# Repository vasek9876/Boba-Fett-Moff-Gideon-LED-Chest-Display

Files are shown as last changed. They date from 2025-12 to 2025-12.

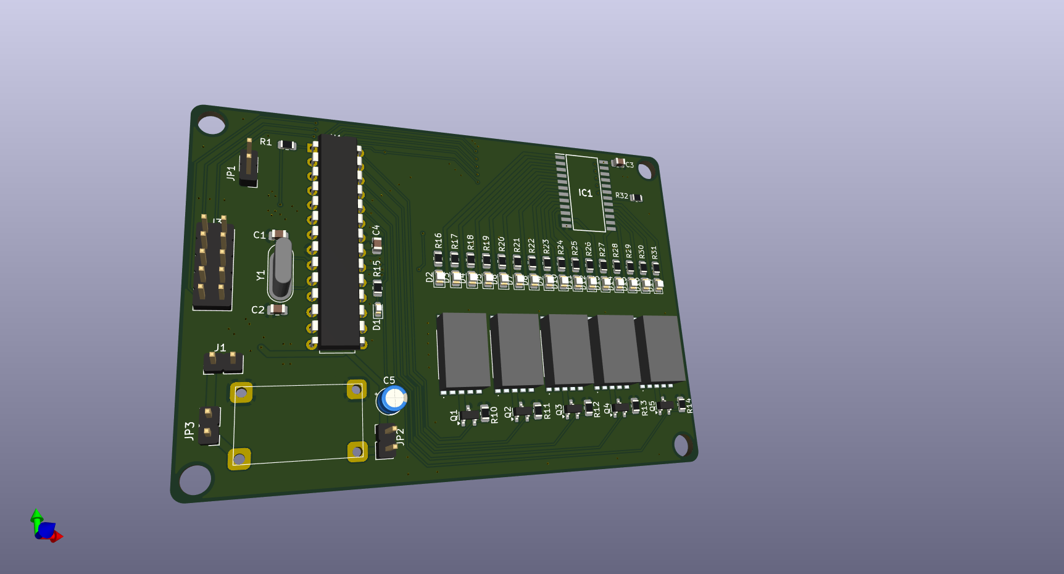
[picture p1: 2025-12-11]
PCB/MODEL/Mandalorian_and_Moff_Gideon.png

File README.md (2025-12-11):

# Boba-Fett-Moff-Gideon-LED-Chest-Display

Boba Fett / Moff Gideon LED Chest Display for cosplay or props.

This product is inspired by these [commercially accessible solution](https://www.etsy.com/au/listing/1456479470/high-quality-boba-fettmoff-gideon-led) - but made for a smaller chestplate
Function implemented to emulate the same functions as in this image - The current version of the code does not implement the last display function.



## Solution





- Multiplexed LED bar display for chest armor effects
- Gradual power-up sequence to detect brownout correctly
- Battery voltage monitoring with low-voltage deep sleep and green LED alert

## Usage
- Power the device with a suitable battery (9 V battery or use a 5–10 V battery, but a 5-18 V battery is suitable)
- LEDs gradually light up on startup when turned ON
- If battery voltage is too low, the circuit enters deep sleep and indicates the error with the green LED and "E" on the first segment display.
- It is possible to connect the powerbank directly to the pins used for the 9 V battery, but the consumption of the circuit is approximately 100 mA, so the circuit is not ready to run on a powerbank continuously (the powerbank turns off after a time because of its internal protection circuit)
  - Some old power banks are ready to be used with this device, but it is not guaranteed.
  - You can use, for example, this device [keep-alive device](https://www.sotabeams.co.uk/usb-battery-pack-keep-alive-load/) for the current version of the device.
- By the calculation, the 9 V battery should keep the device on for 3 - 5 hours, but it depends on the battery capacity and the battery's internal resistance.

## Programming
- Microcontroller: **ATmega328PB**
- Programming via **USB-ASP** device
- Use [AVRDUDE](https://github.com/avrdudes/avrdude) for direct programming; select "USBasp (USBasp ISP and TPI programmer)"
- Fuse settings for this project:
  - Low: `0xE2`
  - High: `0xD9`
  - Extended: `0xFD`
  - Lock Bits: `0xFF`
  - Verify fuses with [Engbedded Fuse Calculator](https://www.engbedded.com/fusecalc/)

- Firmware source code is included in [SW](https://github.com/vasek9876/Boba-Fett-Moff-Gideon-LED-Chest-Display/tree/all/sw)

## Notes

Untitled Diagram (2)

- Ensure proper power supply to avoid brownout during startup (>5 V)
- Multiplexing is handled in firmware
- The rapid switching of LEDs may generate audible noise from the power supply or nearby components; this is normal and does not indicate a fault.

## Goal and further developement

- The goal of this open hw is to make this relatively simple custom device based on AtMega accessible for anyone.
- The current development is stopped, but there are known issues, which will be resolved in a few months.

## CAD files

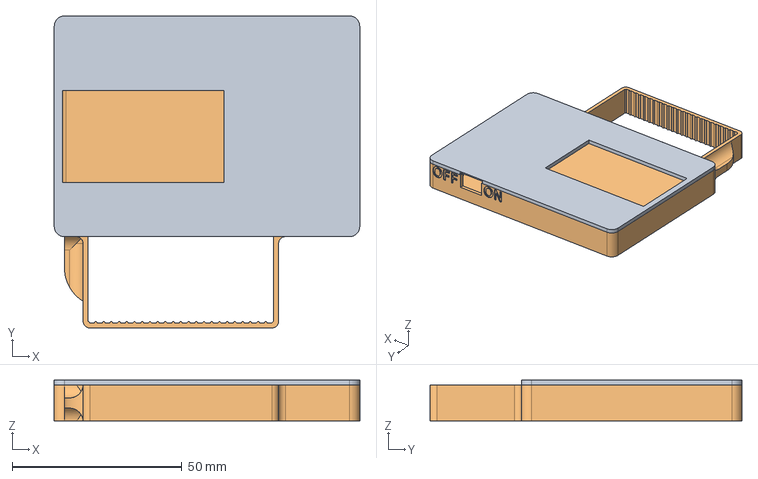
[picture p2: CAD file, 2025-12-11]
hw/box.step
90.0 x 91.9 x 12.0 mm

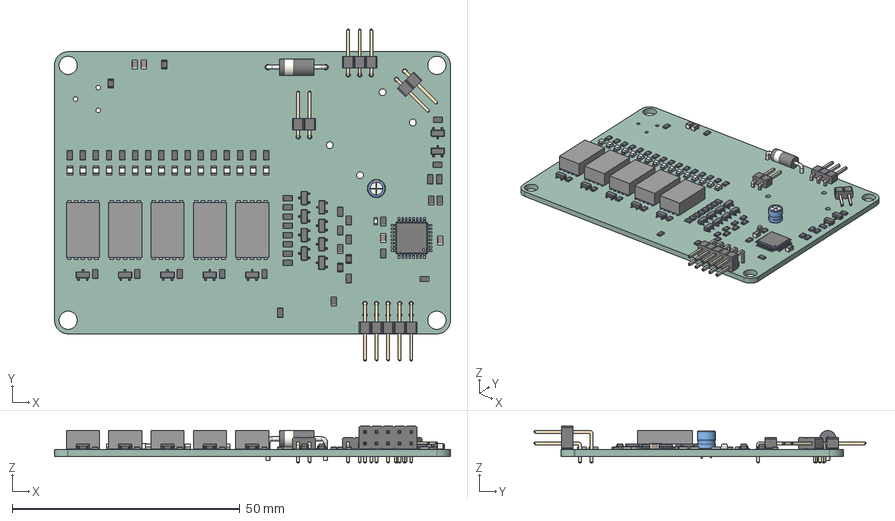
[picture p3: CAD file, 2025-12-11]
PCB/MODEL/Mandalorian_and_Moff_Gideon.step
87.0 x 72.8 x 8.08 mm
R_0805_2012Metric x 50
SOT_23 x 15
D_DO-15_P12.70mm_Horizontal
PinHeader_1x03_P254mm_Horizontal
LED_0805_2012Metric x 16
ASSEMBLY x 5
C_0805_2012Metric x 4
PinHeader_1x02_P254mm_Horizontal x 2
LED_0603_1608Metric
PinHeader_2x05_P254mm_Horizontal
CP_Radial_D40mm_P200mm
TQFP_32_7x7mm_P08mm
Mandalorian_and_Moff_Gideon_PCB

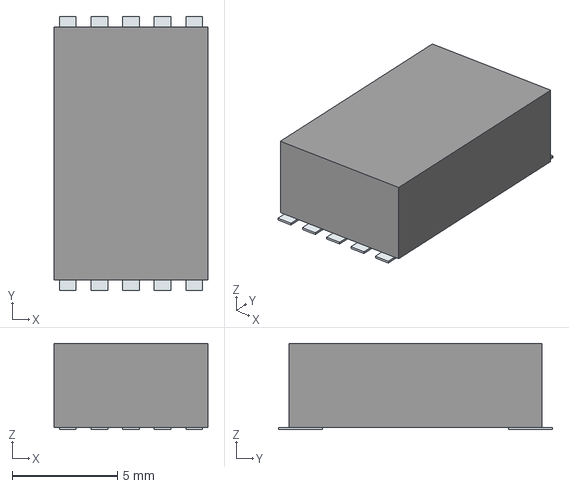
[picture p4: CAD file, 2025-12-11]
PCB/LIB_157112B12700/157112B12700/3D/157112B12700.stp
7.30 x 13.0 x 4.10 mm
Pins

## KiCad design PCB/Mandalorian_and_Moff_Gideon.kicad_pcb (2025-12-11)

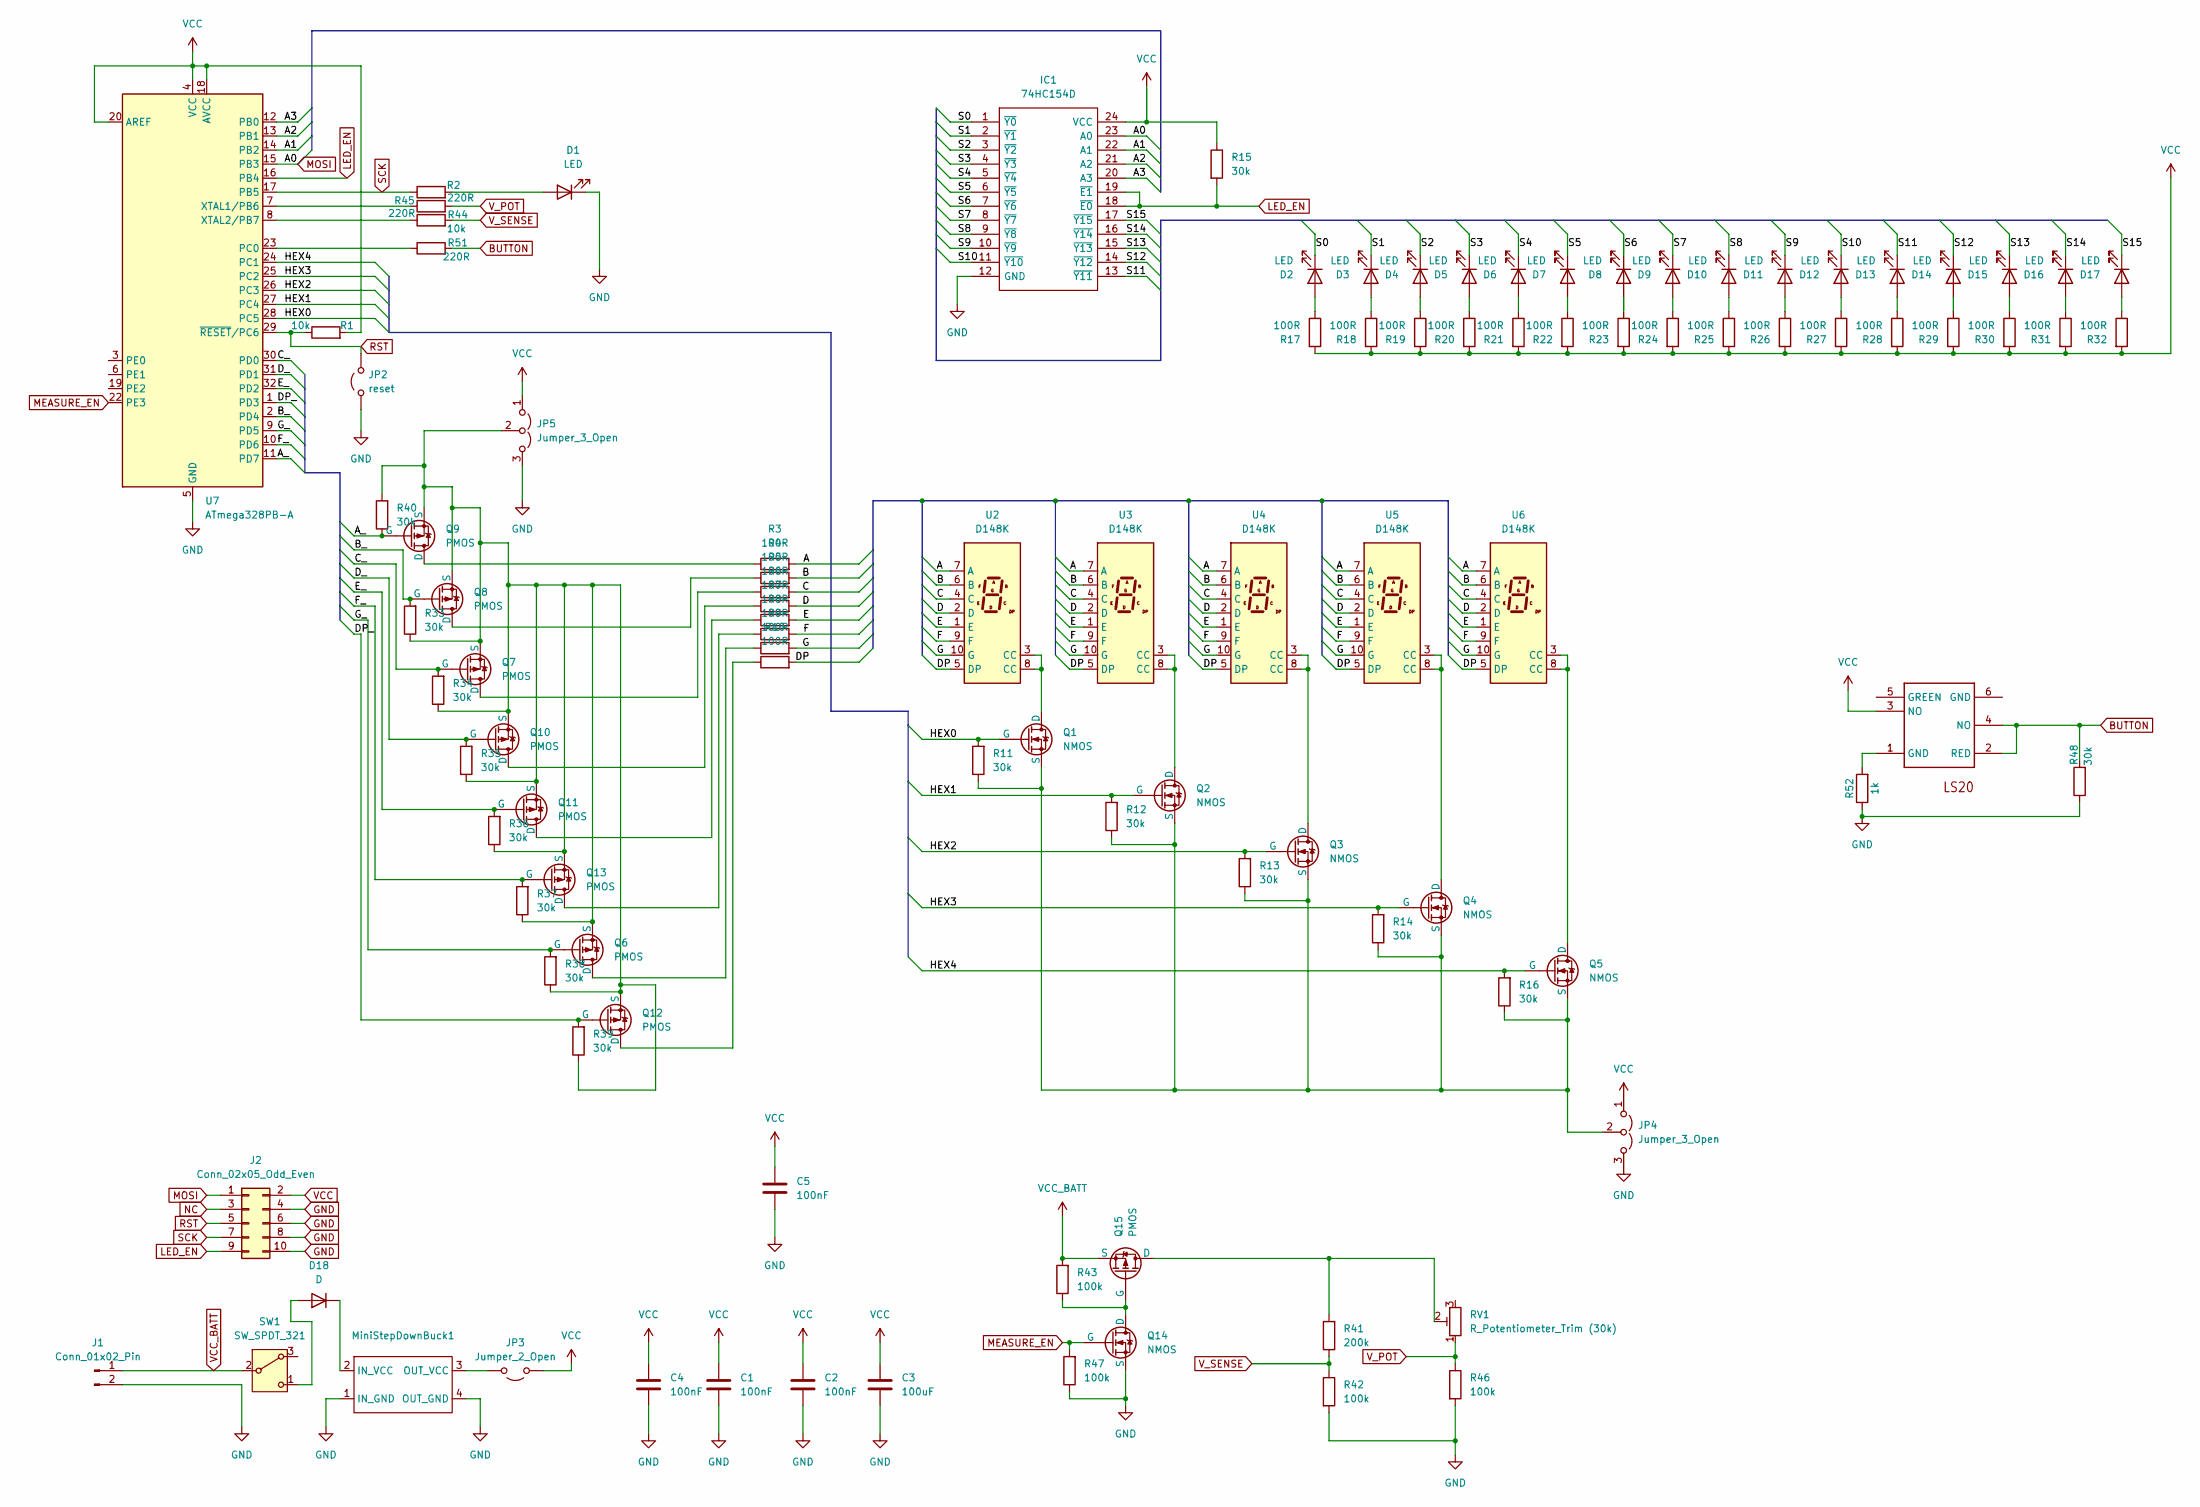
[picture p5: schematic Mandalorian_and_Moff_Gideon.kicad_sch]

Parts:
C1, C2, C4, C5: 100nF; C_0805_2012Metric
C3: 100uF; CP_Radial_D4.0mm_P2.00mm
D1: LED; LED_0603_1608Metric
D2, D3, D4, D5, D6, D7, D8, D9, D10, D11, D12, D13, D14, D15, D16, D17: LED; LED_0805_2012Metric
D18: D; D_DO-15_P12.70mm_Horizontal
IC1: 74HC154D; SOIC127P1032X265-24N; Manufacturer_Part_Number 74HC154D; Mouser Part Number 771-74HC154D
J1: Conn_01x02_Pin; PinHeader_1x02_P2.54mm_Horizontal
J2: Conn_02x05_Odd_Even; PinHeader_2x05_P2.54mm_Horizontal
JP2: reset; SolderJumper-2_P1.3mm_Open_RoundedPad1.0x1.5mm
JP3: Jumper_2_Open; PinHeader_1x02_P2.54mm_Horizontal
JP4, JP5: Jumper_3_Open; SolderJumper-3_P1.3mm_Open_RoundedPad1.0x1.5mm
LS20: LS20
MiniStepDownBuck1: Step_down_360
Q1, Q2, Q3, Q4, Q5, Q14: NMOS; SOT-23
Q6, Q7, Q8, Q9, Q10, Q11, Q12, Q13, Q15: PMOS; SOT-23
R1, R44: 10k; R_0805_2012Metric
R2, R45, R51: 220R; R_0805_2012Metric
R3, R4, R5, R6, R7, R8, R9, R10, R17, R18, R19, R20, R21, R22, R23, R24, R25, R26, R27, R28, R29, R30, R31, R32: 100R; R_0805_2012Metric
R11, R12, R13, R14, R15, R16, R33, R34, R35, R36, R37, R38, R39, R40, R48: 30k; R_0805_2012Metric
R41: 200k; R_0805_2012Metric
R42, R43, R46, R47: 100k; R_0805_2012Metric
R52: 1k; R_0805_2012Metric
RV1: R_Potentiometer_Trim (30k); Potentiometer_Runtron_RM-065_Vertical
SW1: SW_SPDT_321; PinHeader_1x03_P2.54mm_Horizontal
U2, U3, U4, U5, U6: D148K; 157112B12700
U7: ATmega328PB-A; TQFP-32_7x7mm_P0.8mm

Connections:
/A: R3.2, U2.7 (A), U3.7 (A), U4.7 (A), U5.7 (A), U6.7 (A)
/A1: IC1.22 (A1), U7.14 (PB2)
/A2: IC1.21 (A2), U7.13 (PB1)
/A3: IC1.20 (A3), U7.12 (PB0)
/A_: Q9.1 (G), R40.1, U7.11 (PD7)
/B: R4.2, U2.6 (B), U3.6 (B), U4.6 (B), U5.6 (B), U6.6 (B)
/B_: Q8.1 (G), R33.2, U7.2 (PD4)
/C: R5.2, U2.4 (C), U3.4 (C), U4.4 (C), U5.4 (C), U6.4 (C)
/C_: Q7.1 (G), R34.2, U7.30 (PD0)
/D: R6.2, U2.2 (D), U3.2 (D), U4.2 (D), U5.2 (D), U6.2 (D)
/DP: R10.2, U2.5 (DP), U3.5 (DP), U4.5 (DP), U5.5 (DP), U6.5 (DP)
/DP_: Q12.1 (G), R39.2, U7.1 (PD3)
/D_: Q10.1 (G), R35.2, U7.31 (PD1)
/E: R7.2, U2.1 (E), U3.1 (E), U4.1 (E), U5.1 (E), U6.1 (E)
/E_: Q11.1 (G), R36.2, U7.32 (PD2)
/F: R8.2, U2.9 (F), U3.9 (F), U4.9 (F), U5.9 (F), U6.9 (F)
/F_: Q13.1 (G), R37.2, U7.10 (PD6)
/G: R9.2, U2.10 (G), U3.10 (G), U4.10 (G), U5.10 (G), U6.10 (G)
/G_: Q6.1 (G), R38.2, U7.9 (PD5)
/HEX0: Q1.1 (G), R11.2, U7.28 (PC5)
/HEX1: Q2.1 (G), R12.2, U7.27 (PC4)
/HEX2: Q3.1 (G), R13.2, U7.26 (PC3)
/HEX3: Q4.1 (G), R14.2, U7.25 (PC2)
/HEX4: Q5.1 (G), R16.2, U7.24 (PC1)
/S0: D2.1 (K), IC1.1 (~Y0)
/S1: D3.1 (K), IC1.2 (~Y1)
/S2: D4.1 (K), IC1.3 (~Y2)
/S3: D5.1 (K), IC1.4 (~Y3)
/S4: D6.1 (K), IC1.5 (~Y4)
/S5: D7.1 (K), IC1.6 (~Y5)
/S6: D8.1 (K), IC1.7 (~Y6)
/S7: D9.1 (K), IC1.8 (~Y7)
/S8: D10.1 (K), IC1.9 (~Y8)
/S9: D11.1 (K), IC1.10 (~Y9)
/S10: D12.1 (K), IC1.11 (~Y10)
/S11: D13.1 (K), IC1.13 (~Y11)
/S12: D14.1 (K), IC1.14 (~Y12)
/S13: D15.1 (K), IC1.15 (~Y13)
/S14: D16.1 (K), IC1.16 (~Y14)
/S15: D17.1 (K), IC1.17 (~Y15)
BUTTON: LS20.2 (RED), LS20.4 (NO), R48.2, R51.2
GND: C1.2, C2.2, C3.2, C4.2, C5.2, D1.1 (K), IC1.12 (GND), J1.2, J2.4, J2.6, J2.8, J2.10, JP2.1 (A), JP4.3 (B), JP5.3 (B), MiniStepDownBuck1.1 (IN_GND), MiniStepDownBuck1.4 (OUT_GND), Q14.2 (S), R42.2, R46.2, R47.1, R48.1, R52.1, U7.5 (GND), U7.21 (GND)
LED_EN: IC1.18 (~E0), IC1.19 (~E1), J2.9, R15.2, U7.16 (PB4)
MEASURE_EN: Q14.1 (G), R47.2, U7.22 (PE3)
MOSI: IC1.23 (A0), J2.1, U7.15 (PB3)
NC: J2.3
unnamed: D1.2 (A), R2.2
unnamed: D2.2 (A), R17.1
unnamed: D3.2 (A), R18.1
unnamed: D4.2 (A), R19.1
unnamed: D5.2 (A), R20.1
unnamed: D6.2 (A), R21.1
unnamed: D7.2 (A), R22.1
unnamed: D8.2 (A), R23.1
unnamed: D9.2 (A), R24.1
unnamed: D10.2 (A), R25.1
unnamed: D11.2 (A), R26.1
unnamed: D12.2 (A), R27.1
unnamed: D13.2 (A), R28.1
unnamed: D14.2 (A), R29.1
unnamed: D15.2 (A), R30.1
unnamed: D16.2 (A), R31.1
unnamed: D17.2 (A), R32.1
unnamed: D18.2 (A), SW1.1 (C)
unnamed: D18.1 (K), MiniStepDownBuck1.2 (IN_VCC)
unnamed: JP3.2 (B), MiniStepDownBuck1.3 (OUT_VCC)
unnamed: JP4.2 (C), Q1.2 (S), Q2.2 (S), Q3.2 (S), Q4.2 (S), Q5.2 (S), R11.1, R12.1, R13.1, R14.1, R16.1
unnamed: JP5.2 (C), Q6.2 (S), Q7.2 (S), Q8.2 (S), Q9.2 (S), Q10.2 (S), Q11.2 (S), Q12.2 (S), Q13.2 (S), R33.1, R34.1, R35.1, R36.1, R37.1, R38.1, R39.1, R40.2
unnamed: LS20.1 (GND), R52.2
unnamed: Q1.3 (D), U2.3 (CC), U2.8 (CC)
unnamed: Q2.3 (D), U3.3 (CC), U3.8 (CC)
unnamed: Q3.3 (D), U4.3 (CC), U4.8 (CC)
unnamed: Q4.3 (D), U5.3 (CC), U5.8 (CC)
unnamed: Q5.3 (D), U6.3 (CC), U6.8 (CC)
unnamed: Q6.3 (D), R9.1
unnamed: Q7.3 (D), R5.1
unnamed: Q8.3 (D), R4.1
unnamed: Q9.3 (D), R3.1
unnamed: Q10.3 (D), R6.1
unnamed: Q11.3 (D), R7.1
unnamed: Q12.3 (D), R10.1
unnamed: Q13.3 (D), R8.1
unnamed: Q14.3 (D), Q15.1 (G), R43.1
unnamed: Q15.3 (D), R41.2, RV1.2
unnamed: R51.1, U7.23 (PC0)
unnamed: R45.1, U7.7 (XTAL1/PB6)
unnamed: R44.1, U7.8 (XTAL2/PB7)
RST: J2.5, JP2.2 (B), R1.1, U7.29 (~RESET/PC6)
SCK: J2.7, R2.1, U7.17 (PB5)
VCC: C1.1, C2.1, C3.1, C4.1, C5.1, IC1.24 (VCC), J2.2, JP3.1 (A), JP4.1 (A), JP5.1 (A), LS20.3 (NO), R1.2, R15.1, R17.2, R18.2, R19.2, R20.2, R21.2, R22.2, R23.2, R24.2, R25.2, R26.2, R27.2, R28.2, R29.2, R30.2, R31.2, R32.2, U7.4 (VCC), U7.18 (AVCC), U7.20 (AREF)
VCC_BATT: J1.1, Q15.2 (S), R43.2, SW1.2 (B)
V_POT: R45.2, R46.1, RV1.1
V_SENSE: R41.1, R42.1, R44.2

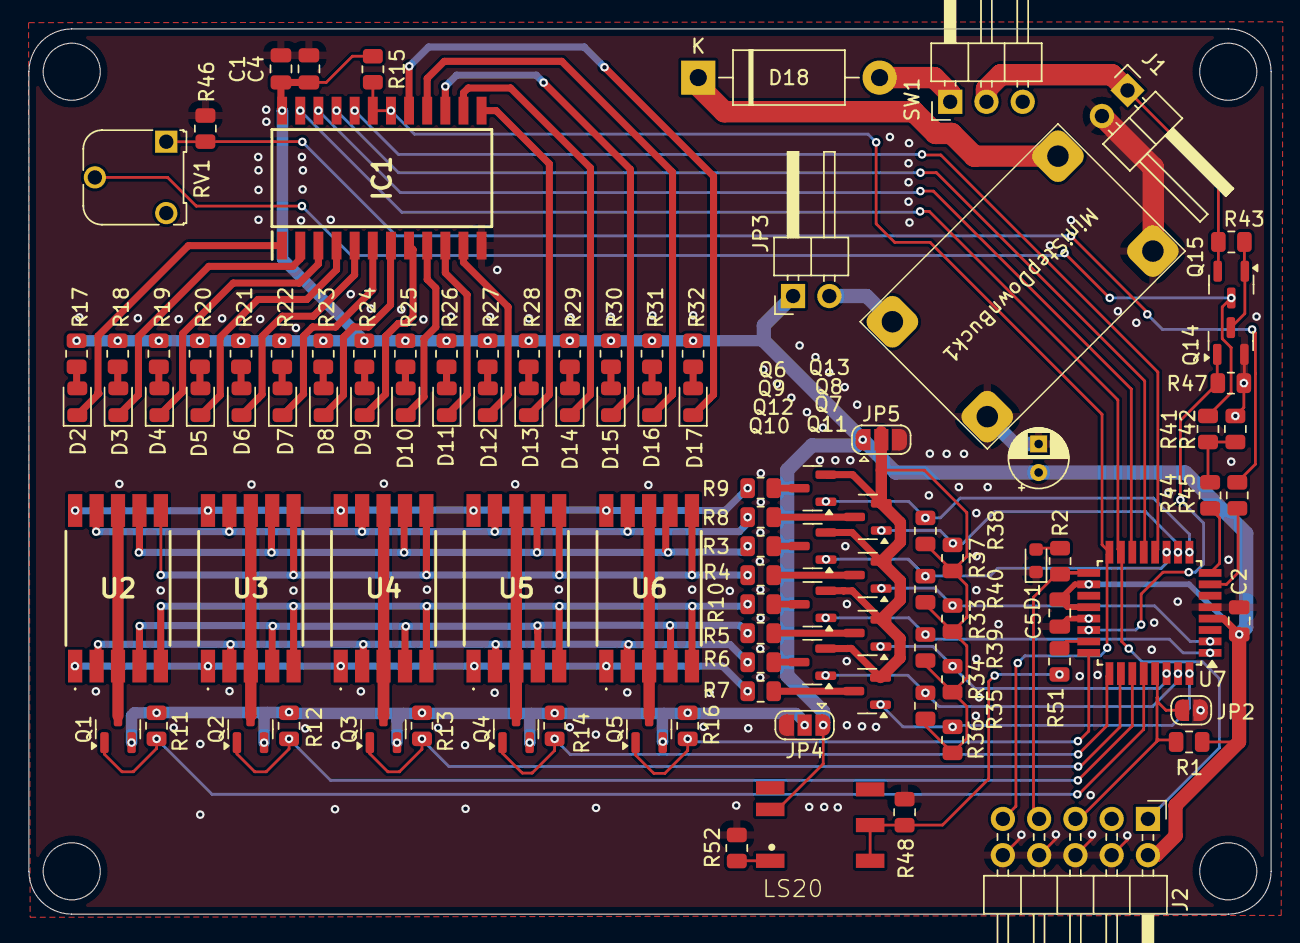
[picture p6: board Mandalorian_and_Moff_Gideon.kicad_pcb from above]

Board: 2 copper layers, 87.0 x 62.0 mm, 105 parts (0 on the bottom side), 92 nets.

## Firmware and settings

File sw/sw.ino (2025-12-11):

#include "defaults.h"
#include "functions.h"
#include "analog.h"
//#include "bod_detect.cpp"

//#define NOP __asm__ __volatile__ ("nop\n\t") // Define the NOP instruction

bool bod_triggered = false;

void setup_bod_flag() {
  uint8_t status = MCUSR;

  // Clear flags immediately after reading to prepare for next event
  MCUSR = 0; 
  bod_triggered = true;
  led_on();

  if (status & (1 << BORF)) {
    bod_triggered = true;
    led_on();
    // Brown-out Reset occurred
    // {Link: www.avrfreaks.net https://www.avrfreaks.net/s/topic/a5C3l000000UY10EAG/t144548}
  }

  if (status & (1 << PORF)) {
    bod_triggered = false;
    led_off();
    // Power-on Reset occurred (also clears BORF if it happened)
  }
}

void getVoltageDigits(float v, int digits[5]) {
    int scaled = v*10000*2 + OFFSET*1000;

    digits[0] = (scaled / 1000) % 10;
    digits[1] = (scaled / 100)  % 10;
    digits[2] = (scaled / 10)   % 10;
    digits[3] =  scaled % 10;
    digits[4] = 0; 
}

void preloop() {
  float v;
  int digits[5];
  for (int n = 0; n < 3; n++) {
    v = readVoltage();
    getVoltageDigits(v, digits);

    for (int k = 0; k < 100; k++) {
      lcd_write(0, PATTERN_U);
      lcd_write(1, pattern_numbers[digits[3]]);
      lcd_write(2, pattern_numbers[digits[2]]);
      lcd_write(3, pattern_numbers[digits[1]]);
      lcd_write(4, pattern_numbers_DP[digits[0]]);
    }
  }
}

void setup() {
  setup_bod_flag();

  // ----------------- NEW --------------------
  DDRB |= (1 << LED_PIN); // led setup as output

  // ADC MEASURE
  // 1. Set PC0 (ADC0) as input pin
  // --- ADC MĚŘENÍ ---
  // 1. Nastavte PC0 (ADC0) jako vstup (ruční nastavení DDRC)
  DDRC &= ~(1 << PC0); 

  // 2. Nastavte Referenci (AVcc) a kanál (ADC0)
  ADMUX = (1 << REFS0); 
  
  // 3. Povolte ADC, Prescaler 128 a vynulujte ADCSRB
  ADCSRA = (1 << ADEN) | (1 << ADPS2) | (1 << ADPS1) | (1 << ADPS0);
  ADCSRB = 0; // K zamezení interních měření

  // Set PE3 as OUTPUT and initialize to LOW
  DDRE |= (1 << MEASURE_EN_BIT);  // PE3 as output
  PORTE &= ~(1 << MEASURE_EN_BIT);  // Initialize to LOW

  DDRD = 0xFF;
  LCD_DDR |= LCD_MASK;  // outputs
  BAR_DDR |= BAR_MASK;  // outputs
  BAR_EN_DDR |= (1 << BAR_EN_BIT);

  // Start with all off
  LCD_PORT &= ~LCD_MASK;
  BAR_PORT &= ~BAR_MASK;

  // ENABLE
  //BAR_EN_PORT &= ~(1 << BAR_EN_BIT);

  //DISABLE
  BAR_EN_PORT |= (1 << BAR_EN_BIT);

  // Configure Timer1 once
  TCCR1A = 0;            // Normal mode
  TCCR1B = (1 << CS10);  // Prescaler = 1

  if (bod_triggered)
  {
    for (int n = 0; n < 1; n++) {
      for (int k = 0; k < 100; k++) {
      lcd_write(4, PATTERN_E);
      delay(1);
      }
    }
  }
  else
  {
    bar_test();

    preloop();
  }

  ADCSRA &= ~(1 << ADEN); // disable ADC


  PRR = (1 << PRTWI) |    // Disable TWI (I2C)
          (1 << PRSPI) |    // Disable SPI
          (1 << PRUSART0) | // Disable USART (Serial)
          (1 << PRTIM2);   // Disable Timer 2
          //(1 << PRTIM0);    // Disable Timer 0 (Timer 1 is kept for LCD/Bar timing)
  

}

void loop() {
  if (bod_triggered) {
    set_sleep_mode(SLEEP_MODE_PWR_SAVE);
    sleep_enable();
  }
  else
  {
  for (int i = 0; i < REPEAT_FUNC1; i++) {
    call_function(pattern5, 9);
  }

  for (int i = 0; i < REPEAT_FUNC2; i++) {
    call_function(pattern2, 6);
  }

  for (int i = 0; i < REPEAT_FUNC3; i++) {
    call_function(pattern1, 11);
  }

  BAR_EN_PORT |= (1 << BAR_EN_BIT);
  for (int i = 0; i < REPEAT_FUNC4; i++) {
    call_bare_function(pattern4);
  }

  for (int i = 0; i < REPEAT_FUNC5; i++) {
    call_function(pattern2, 3);
  }

  for (int i = 0; i < REPEAT_FUNC6; i++) {
    call_function(pattern3, 0);
  }
  }
}

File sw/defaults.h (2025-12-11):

#ifndef defaults_h
#define defaults_h

#include <avr/io.h>

#ifdef OLD

// 88888
#define PATTERN_51 0b11101111
#define PATTERN_52 0b11101111
#define PATTERN_53 0b11101111
#define PATTERN_54 0b11101111
#define PATTERN_55 0b11101111

// DUEPI
#define PATTERN_21 0b00000010
#define PATTERN_22 0b10001111
#define PATTERN_23 0b11000111
#define PATTERN_24 0b11101010
#define PATTERN_25 0b11101001

// AEAOE
#define PATTERN_11 0b10000011
#define PATTERN_12 0b11101100
#define PATTERN_13 0b10101101
#define PATTERN_14 0b11000111
#define PATTERN_15 0b10100111

// caj
#define PATTERN_41 0b00000101
#define PATTERN_42 0b10000010
#define PATTERN_43 0b01000100
#define PATTERN_44 0b00100010
#define PATTERN_45 0b00001001

// DUEPI again

// H5291
#define PATTERN_31 0b10000010
#define PATTERN_32 0b00101111
#define PATTERN_33 0b11001101
#define PATTERN_34 0b01100011
#define PATTERN_35 0b10101011

#else

// 88888
#define PATTERN_51 0b00001000
#define PATTERN_52 0b00001000
#define PATTERN_53 0b00001000
#define PATTERN_54 0b00001000
#define PATTERN_55 0b00001000

// DUEPI
#define PATTERN_21 0b10111111
#define PATTERN_22 0b00001011
#define PATTERN_23 0b00011001
#define PATTERN_24 0b10101000
#define PATTERN_25 0b11001000

// AEAOE
#define PATTERN_11 0b10011011
#define PATTERN_12 0b01101000
#define PATTERN_13 0b01001010
#define PATTERN_14 0b00011001
#define PATTERN_15 0b00011010

// caj
#define PATTERN_41 0b01011111
#define PATTERN_42 0b10111011
#define PATTERN_43 0b01111101
#define PATTERN_44 0b10111110
#define PATTERN_45 0b11001111

// DUEPI again

// H5291
#define PATTERN_31 0b10111011
#define PATTERN_32 0b00001110
#define PATTERN_33 0b01001001
#define PATTERN_34 0b10011100
#define PATTERN_35 0b10001010

// now afgbhedc (default abcdefgh)

#define PATTERN_0 0b00101000  // 0 // OK
#define PATTERN_1 0b10111011  // 1 // OK
#define PATTERN_2 0b01001001  // 2 // OK
#define PATTERN_3 0b01001100  // 3 // OK
#define PATTERN_4 0b10001110  // 4 // OK
#define PATTERN_5 0b00011100  // 5
#define PATTERN_6 0b00011000  // 6
#define PATTERN_7 0b01101110  // 7
#define PATTERN_8 0b00001000  // 8
#define PATTERN_9 0b00001110  // 9
#define PATTERN_E 0b00011001  // E

#define PATTERN_0_DP 0b00100000  // 0 // OK
#define PATTERN_1_DP 0b10110011  // 1 // OK
#define PATTERN_2_DP 0b01000001  // 2 // OK
#define PATTERN_3_DP 0b01000100  // 3 // OK
#define PATTERN_4_DP 0b10000110  // 4 // OK
#define PATTERN_5_DP 0b00010100  // 5
#define PATTERN_6_DP 0b00010000  // 6
#define PATTERN_7_DP 0b01100110  // 7
#define PATTERN_8_DP 0b00000000  // 8
#define PATTERN_9_DP 0b00000110  // 9

#define PATTERN_U 0b10101000

#endif

#ifdef TEST



#define PATTERN_11 0b01111111
#define PATTERN_12 0b01110111
#define PATTERN_13 0b01111011
#define PATTERN_14 0b01111101
#define PATTERN_15 0b01111110

#endif

// in sec
#define REPEAT_FUNC1 27*2 // 0.49
#define REPEAT_FUNC2 28*2 // 0.51
#define REPEAT_FUNC3 26*2 // 0.48
#define REPEAT_FUNC4 40*2 // 0.72  
#define REPEAT_FUNC5 30*2 // 0.54
#define REPEAT_FUNC6 27*2 // 0.50

// digits

const byte DIGITS[10] = {
    PATTERN_0,
    PATTERN_1,
    PATTERN_2,
    PATTERN_3,
    PATTERN_4,
    PATTERN_5,
    PATTERN_6,
    PATTERN_7,
    PATTERN_8,
    PATTERN_9
};


const byte bar_map[16][4] = {
  // D, B, A, C (DCBA - 1111)
  {0,0,0,0},
  {0,0,1,0},
  {0,1,0,0},
  {0,1,1,0},
  {0,0,0,1},
  {0,0,1,1},
  {0,1,0,1},
  {0,1,1,1},

  {1,0,0,0},
  {1,0,1,0},
  {1,1,0,0},
  {1,1,1,0},
  {1,0,0,1},
  {1,0,1,1},
  {1,1,0,1},
  {1,1,1,1},
};

// Old
#ifdef OLD
const byte bar_map[16][4] = {
    {0,0,0,1},
    {0,1,0,0},
    {0,0,1,0},
    {0,0,0,0},
    {1,0,0,0},
    {1,1,0,0},
    {0,1,0,1},
    {1,1,0,1},
    {0,0,1,0},
    {1,0,1,0},
    {0,0,1,1},
    {1,0,1,1},
    {0,1,1,0},
    {1,1,1,0},
    {0,1,1,1},
    {1,1,1,1}
};
#endif



const byte pattern_numbers[] = {PATTERN_0, PATTERN_1, PATTERN_2, PATTERN_3, PATTERN_4,
                                PATTERN_5, PATTERN_6, PATTERN_7, PATTERN_8, PATTERN_9};

const byte pattern_numbers_DP[] = {PATTERN_0_DP, PATTERN_1_DP, PATTERN_2_DP, PATTERN_3_DP, PATTERN_4_DP,
                                PATTERN_5_DP, PATTERN_6_DP, PATTERN_7_DP, PATTERN_8_DP, PATTERN_9_DP};


const byte pattern1[] = {PATTERN_11, PATTERN_12, PATTERN_13, PATTERN_14, PATTERN_15};
const byte pattern2[] = {PATTERN_21, PATTERN_22, PATTERN_23, PATTERN_24, PATTERN_25};
const byte pattern3[] = {PATTERN_31, PATTERN_32, PATTERN_33, PATTERN_34, PATTERN_35};
const byte pattern4[] = {PATTERN_41, PATTERN_42, PATTERN_43, PATTERN_44, PATTERN_45};
const byte pattern5[] = {PATTERN_51, PATTERN_52, PATTERN_53, PATTERN_54, PATTERN_55};



// LED pin
#define LED_PIN PB5

// LCD segments on PORTC bits 5..1
// const int lcd_addr[] = { A5, A4, A3, A2, A1 };  // Segments: PC5,PC4,PC3,PC2,PC1
#define LCD_PORT PORTC
#define LCD_DDR DDRC
#define LCD_MASK ((1 << PC5) | (1 << PC4) | (1 << PC3) | (1 << PC2) | (1 << PC1))

#define NUM_SEG 5  // Number of LCD segments

// Bar LEDs on PORTB bits 0,2,3,1 (in that order)
// const int bar_leds[] = { 8, 10, 11, 9 };  // PB0, PB2, PB3, PB1
#define BAR_PORT PORTB
#define BAR_DDR DDRB
#define BAR_MASK ((1 << PB0) | (1 << PB2) | (1 << PB3) | (1 << PB1))

// map bits to actual PORTB bits
static const uint8_t barBits[4] = { (1 << PB0), (1 << PB2), (1 << PB3), (1 << PB1) };

// const int bar_leds_en = 12;  // PB4
#define BAR_EN_PORT PORTB
#define BAR_EN_DDR DDRB
#define BAR_EN_BIT PB4

#endif

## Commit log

2025-12-11 PCB
    kicad - PCB last version
    - badly routed V_BAT measurement and the analog pins - they are not at analog inputs
    - the reverse polarity protection is not ok with deiode - next iteration should have the ideal diode using Pmos
    [157112B12700.stp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]
2025-12-11 Last firmware with loading and voltage indication
    - In the last firmware, the first step tries to turn on all bar LEDs gradually, which is necessary to slowly increase power consumption and check for brownout detection.
    - After the loading bar, the battery voltage is measured three times, typically ranging from about 5.000 V to 9.999 V. If the voltage is lower, the circuit enters deep sleep, and the green LED on the board turns on with the signal E. (The led is hidden uder the cover - it just do not run)
    - After these steps, the normal program starts running.
    [analog.cpp, analog.h, defaults.h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]
2025-12-11 hw - 3D model
    [box.step]
